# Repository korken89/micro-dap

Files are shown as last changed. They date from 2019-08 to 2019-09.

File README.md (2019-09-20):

# Micro CMSIS-DAP Probe (µDAP)

A small [CMSIS-DAP](https://arm-software.github.io/CMSIS_5/DAP/html/index.html) probe, based on the pinout of the [dap42 firmware](https://github.com/devanlai/dap42).

## Changes

### v1.0

* First release

## Resources

### Schematics

TODO

### Programming instructions

The first time you connect the probe (if it has not been flashed yet) it will come up in DFU bootloader mode, and the following instructions will flash the probe:

```console
# Clone and build the firmware
git clone --recursive https://github.com/devanlai/dap42.git
cd dap42
make

# Flash the probe
cd build
dfu-util -d 1209:da42,0483:df11  -a 0 -s 0x08000000:leave -D DAP42.bin
```

Which should give the following output:

```console
# ....

DFU mode device DFU version 011a
Device returned transfer size 2048
DfuSe interface name: "Internal Flash  "
Downloading to address = 0x08000000, size = 15764
Download	[=========================] 100%        15764 bytes
Download done.
File downloaded successfully
Transitioning to dfuMANIFEST state
```

Now the probe is ready to use with `OpenOCD` using the following config file for `nrf52`, but you can replace it with any supported target:

```
# openocd_dap.cfg

source [find interface/cmsis-dap.cfg]
transport select swd
source [find target/nrf52.cfg]
```

### Usage

Using the previous config:

```console
openocd -f openocd_dap.cfg
```

Should give an output similar to:

```console
Open On-Chip Debugger 0.10.0+dev-00924-g16496488d (2019-08-18-15:42)
Licensed under GNU GPL v2
For bug reports, read
	http://openocd.org/doc/doxygen/bugs.html
Info : Listening on port 6666 for tcl connections
Info : Listening on port 4444 for telnet connections
Info : CMSIS-DAP: SWD  Supported
Info : CMSIS-DAP: FW Version = 1.0
Info : CMSIS-DAP: Interface Initialised (SWD)
Info : SWCLK/TCK = 1 SWDIO/TMS = 1 TDI = 0 TDO = 0 nTRST = 0 nRESET = 0
Info : CMSIS-DAP: Interface ready
Info : clock speed 1000 kHz
Info : SWD DPIDR 0x2ba01477
Info : nrf52.cpu: hardware has 6 breakpoints, 4 watchpoints
Info : nrf52.cpu: external reset detected
Info : Listening on port 3333 for gdb connections
```

### Images

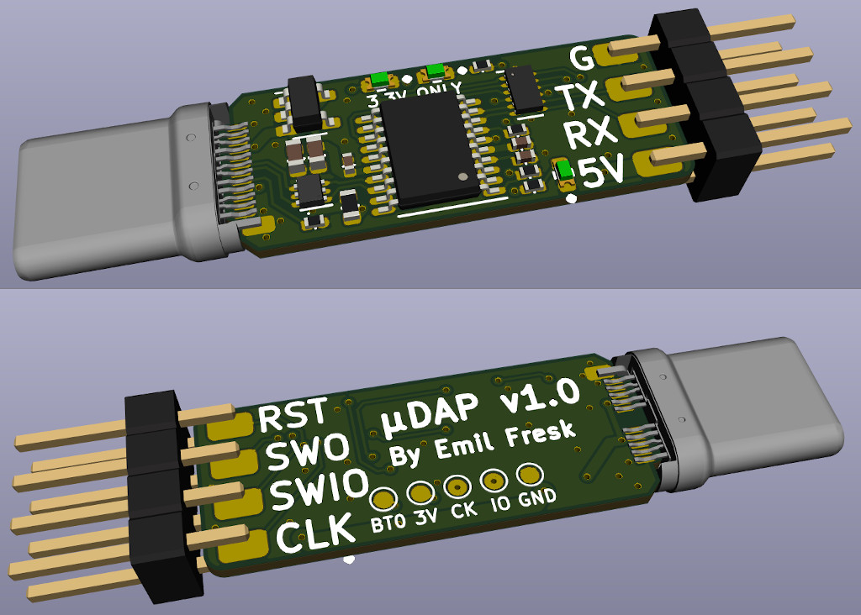
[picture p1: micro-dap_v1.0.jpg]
Render


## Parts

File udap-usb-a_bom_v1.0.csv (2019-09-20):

Reference | Value | Footprint | Datasheet | MFPN
P101 | USB_A | usb:USB_A_1001-011-01101 |  | 1001-011-01101
C4 | 100n | passive:C_0402 | ~
C3 | 100n | passive:C_0402 | ~
U2 | MIC5245-3.3YM5 | sot:SOT-23-5 | http://ww1.microchip.com/downloads/en/devicedoc/mic5205.pdf
C2 | 4.7u | passive:C_0603 | ~
C5 | 4.7u | passive:C_0603 | ~
R1 | 470 | passive:R_0402 | ~
F1 | MF-FSMF050X-2 | passive:R_0603 | http://www.bourns.com/docs/Product-Datasheets/mffsmf.pdf
C1 | 100n | passive:C_0402 | ~
U4 | NUF2042XV6T1G | dfn:DFN-6-1EP_1.2x1.6mm_P0.5mm | http://www.onsemi.com/pub/Collateral/NUF2030XV6-D.PDF
D2 | LTST-C191KGKT | leds:LEDC1608X60 | ~
R2 | 470 | passive:R_0402 | ~
U202 | STM32F042F6Px | sop:TSSOP-20_4.4x6.5mm_P0.65mm | http://www.st.com/st-web-ui/static/active/en/resource/technical/document/datasheet/DM00105814.pdf
D201 | LTST-C191KGKT | leds:LEDC1608X60 | ~
R202 | 470 | passive:R_0402 | ~
R201 | 5.1k | passive:R_0402 | ~
U201 | NUF6401MNT1 | dfn:DFN-12-1EP_1.35x3mm_P0.5mm | https://www.onsemi.cn/pub/Collateral/NUF6401-D.PDF
J201 | 2x4 pin header | connectors:2x4_2.54mm_side | ~
D1 | LTST-C191KGKT | leds:LEDC1608X60 | ~

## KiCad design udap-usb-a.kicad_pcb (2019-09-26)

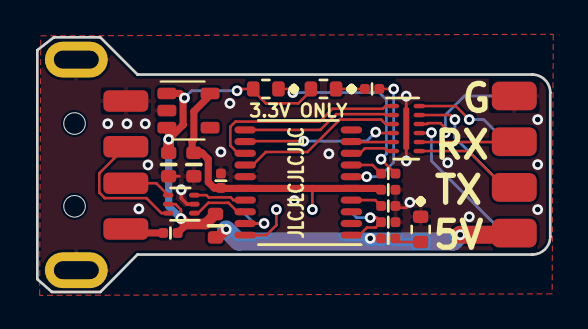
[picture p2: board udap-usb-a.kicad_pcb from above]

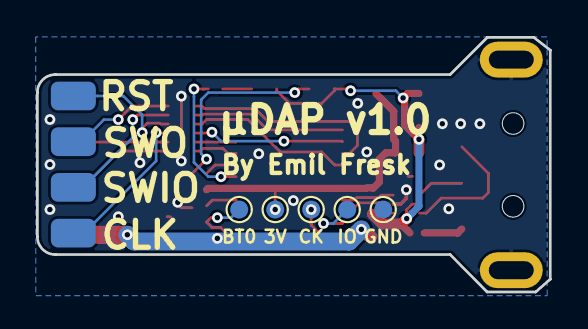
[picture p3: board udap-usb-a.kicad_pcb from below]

Board: 2 copper layers, 28.5 x 14.1 mm, 25 parts (5 on the bottom side), 30 nets.

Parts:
C1, C3, C4: 100n; C_0402
C2, C5: 4.7u; C_0603
D1, D2, D201: LTST-C191KGKT; LEDC1608X60
F1: MF-FSMF050X-2; R_0603
FB101: Ferrite_Bead_Small; R_0402
J201: Conn_02x04_Counter_Clockwise; 2x4_2.54mm_side
P101: USB_A; USB_A_1001-011-01101
R1, R2, R202: 470; R_0402
R201: 5.1k; R_0402
TP1, TP2, TP3, TP201, TP202: Test_Point; TestPoint_Pad_D1.0mm
U2: MIC5245-3.3YM5; SOT-23-5
U4: NUF2042XV6T1G; DFN-6-1EP_1.2x1.6mm_P0.5mm
U201: NUF6401MNT1; DFN-12-1EP_1.35x3mm_P0.5mm
U202: STM32F042F6Px; TSSOP-20_4.4x6.5mm_P0.65mm

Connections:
+3V3: C3.1, C4.1, C5.1, TP201.1, U2.5, U202.5, U202.16
+5V: C2.1, D1.2, D201.2, F1.2, FB101.1, U2.1, U2.3, U4.5
/DM: P101.2, U4.4
/DP: P101.3, U4.6
/core/BOOT0: R201.1, TP202.1, U202.1
/core/DM_P: U4.3, U202.17
/core/DP_P: U4.1, U202.18
/core/LED0: R1.1, U202.6
/core/LED1: R202.1, U202.7
/core/NRST: C1.2, U202.4
/core/SWCLK: TP2.1, U202.20
/core/SWDIO: TP1.1, U202.19
/core/TGT_RST: U201.3, U202.14
/core/TGT_RSTo: J201.8, U201.10
/core/TGT_RX: U201.6, U202.8
/core/TGT_RXo: J201.2, U201.7
/core/TGT_SWCLK: U201.4, U202.12
/core/TGT_SWCLKo: J201.5, U201.9
/core/TGT_SWDIO: U201.2, U202.11
/core/TGT_SWDIOo: J201.6, U201.11
/core/TGT_SWO: U201.1, U202.13
/core/TGT_SWOo: J201.7, U201.12
/core/TGT_TX: U201.5, U202.9
/core/TGT_TXo: J201.3, U201.8
GND: C1.1, C2.2, C3.2, C4.2, C5.2, D2.1, J201.4, P101.4, P101.5, R201.2, TP3.1, U2.2, U4.2, U201.13, U202.15
unnamed: D1.1, R1.2
unnamed: D2.2, R2.2
unnamed: D201.1, R202.2
unnamed: F1.1, J201.1, R2.1
unnamed: FB101.2, P101.1

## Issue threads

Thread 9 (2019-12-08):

Expose 3.3V somehow?

jonas-schievink, 2019-12-08:
µDAP has been working great for me so far, but it has one annoyance: It only exposes 5V on the pin header, but many breakouts and chips need a 3.3V supply voltage instead. It would be great if this could somehow be exposed.

I realize that there's no free pin left, so there's a few options:

* Expose 3.3V *instead* of 5V (if it is deemed more useful than 5V)
* Make the board larger to fit a 5x2 pin header
* Use a denser, but jumper-wire-incompatible connector

None of these sound *terribly* appealing to me, unfortunately :/

korken89, 2019-12-11:
Hmm, this would be good.
I'm thinking about going up to a 2x5 header instead, as I might need to increase the size of the board to fit the larger MCU to get SWO support from dap42.
Another thing is to have a lone via that can fit a single pin from a header which users can add if they want 3.3v.

Not sure though, as you say none really sounds that appealing. :P

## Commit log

2019-08-13 Minor fix
    [core.sch, udap.kicad_pcb, udap.sch]
2019-08-22 Update text and links from µBMP to µDAP
    [core.sch, udap.sch]
2019-08-22 Rotate D2 to move its silk screen in-bounds
    [udap.kicad_pcb]
2019-08-22 Fix BT0 test-point traces
    [udap.kicad_pcb]
2019-08-23 Move the testpoints towards the USB connector
    [udap.kicad_pcb]
2019-08-23 Rename files to indicate USB-A version
    [udap-usb-a.kicad_pcb, udap-usb-a.sch]
2019-08-23 Amend schematic for USB-A version
    [udap-usb-a.sch]
2019-08-23 Update PCB for USB-A version
    [udap-usb-a.kicad_pcb]
2019-08-23 Rename files to indicate USB-C version
    [udap-usb-c.kicad_pcb, udap-usb-c.sch]
2019-09-11 Added BOM
    [udap-usb-a_bom_v1.0.csv]
2019-09-12 Spaced 4.7u apart more, now easier to solder
    [udap-usb-a.kicad_pcb, udap-usb-c.kicad_pcb]
2019-09-20 Fixed bom error
    [udap-usb-a.sch, udap-usb-a_bom_v1.0.csv]
2019-09-20 Add JLCPCB Order Number placeholder
    This adds silkscreen under the MCU saying "JLCJLCJLCJLC". When ordering
    with JLCPCB, they'll replace this with the order number. If this isn't
    done, the order number will be placed somewhere random where it can
    potentially be seen after assembly.
    Since this is purely for a slight convenience when using JLCPCB, I can
    also see just not doing this.
    Also see:
    https://support.jlcpcb.com/article/28-how-to-put-jlc-production-id-at-a-specified-area-on-the-pcb
    [udap-usb-a.kicad_pcb]
2019-09-20 Fix datasheet URL for the regulator
    It used to link to a different regulator that could supply much less
    current
    [core.sch, udap-usb-a.sch]
2019-09-25 Swap TX and RX on silkscreen
    [udap-usb-c.kicad_pcb]
2019-09-25 Also fix USB-A version
    [udap-usb-a.kicad_pcb]
2019-09-26 Added ferrite bead on 5V, PC EMI -> TARGET issue mitigation
    [core.sch, udap-usb-a.kicad_pcb, udap-usb-a.sch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]
